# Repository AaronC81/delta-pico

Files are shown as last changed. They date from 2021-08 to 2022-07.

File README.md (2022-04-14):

# Delta Pico

The Delta Pico is a **powerful scientific calculator built around the Raspberry
Pi Pico**.

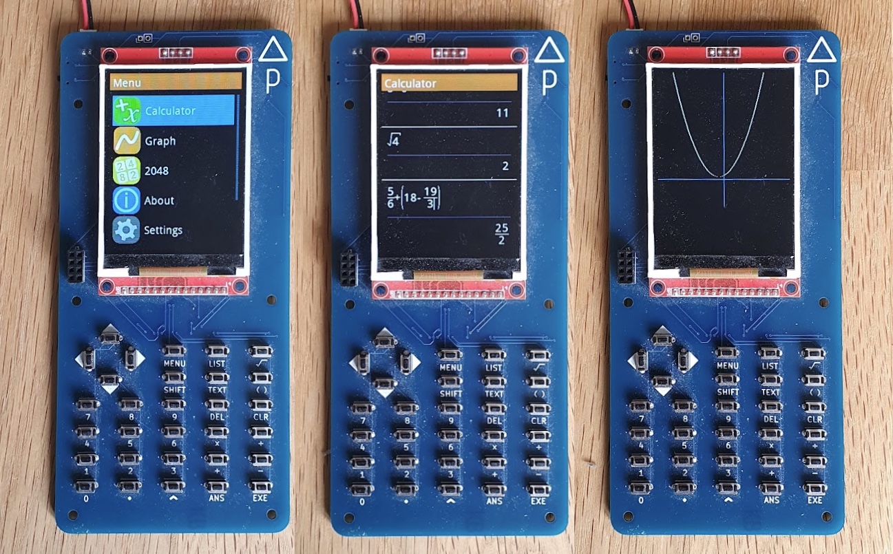
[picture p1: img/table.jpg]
Three images of the Delta Pico calculator on a wooden surface. The first shows the menu interface, with a list of applications such as Calculator and Graph. The second shows the Calculator app, with an expression being edited. The third shows the Graph app, with a parabolic graph plot.


A follow-on project from my [Delta
M0](https://github.com/AaronC81/delta-m0), this calculator is much larger
and significantly more capable, with a 2.8" 240x320 colour display and 30 keys.

The Delta Pico is powered by the [rbop](https://github.com/AaronC81/rbop)
mathematical engine, for gorgeous textbook-style input.

The Delta Pico's software is written in Rust. The hardware abstraction layer is
separate to the user software, theoretically allowing the operating system to
run on other hardware which supports embedded Rust!

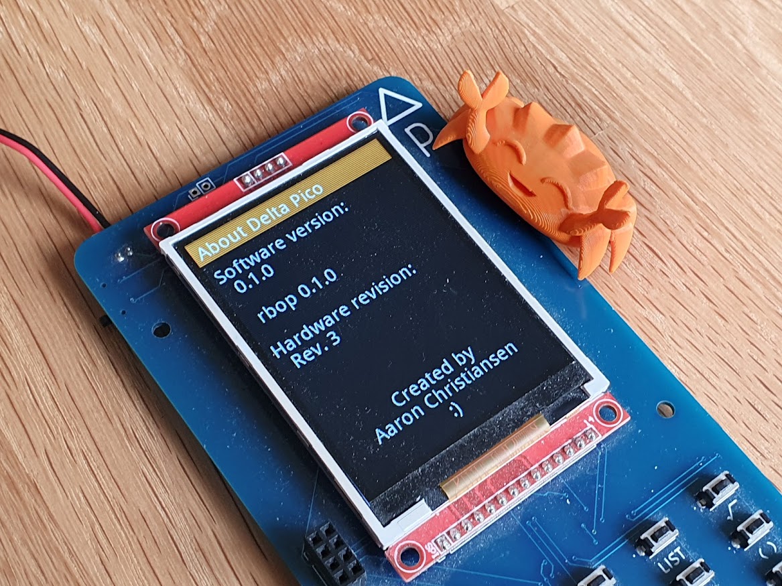
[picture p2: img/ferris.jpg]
Ferris, the Rust mascot, a crab, sitting on top of the Delta Pico


## Building

### Dependencies

You will likely need a bleeding-edge checkout of rbop, so you should check this
out too and adjust the path in `rust/Cargo.toml` accordingly.

This project has a dependency on FontForge, which is used for compiling fonts
into bitmaps. Install FontForge, and then set the `DELTA_PICO_FFPYTHON`
environment variable to point to its included `ffpython` executable. If you've
done this right, you should be able to run `$DELTA_PICO_FFPYTHON` in your 
terminal (or `%DELTA_PICO_FFPYTHON%` on Windows) and get a Python interactive
prompt.

The build script also uses [elf2uf2-rs](https://github.com/JoNil/elf2uf2-rs) to
flash software to the Pico, so be sure to install this.

### Building and Flashing

With all of the above dependencies sorted, cd into `rust-hal` and run:

```
cargo run
```

With a Pico connected in bootloader mode, this should build the project and
flash it onto your Pico.

## Hardware

The KiCad files for the Delta Pico hardware can be found in the `cad` directory.

There is one error with the first hardware revision; a missing trace in the
button matrix, between the down arrow button and diode D8. This can be easily
fixed with a small piece of wire:

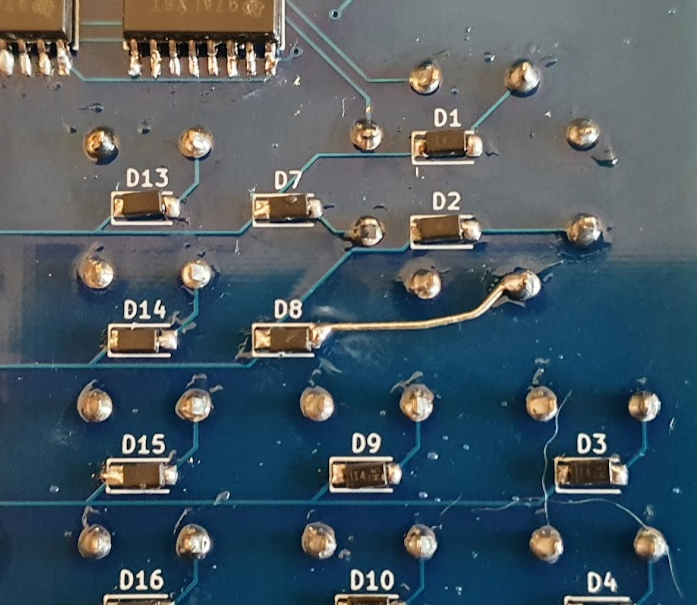
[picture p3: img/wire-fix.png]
A small piece of wire between the down arrow button and diode D8.


## Changelog
### Revision 1
- Initial revision!

### Revision 2
- Add I2C EEPROM chip
- Fix missing trace from "down" button to diode
- Connect display SD pins
- Move Pico further to the side to accommodate SD pins
- Rotate and move expansion socket to not be behind the display

### Revision 3
- Migrate to KiCad 6
- Button layout tweaks
    - The `(` key has been removed and merged into the `)` key to form a single `( )` key
        - rbop treats brackets as a block element, so it isn't possible to have a non-paired
          bracket
        - This means there is no reason to have a separate key for each bracket
    - In place of the `(` key, there is a new `TEXT` key
        - This will be used to toggle a multi-tap text entry mode on the numeric keypad
- Replace the expansion socket with a new debug port
    - 8 pins (4x2) rather than 4 pins
    - 2 of the extra pins are SWCLK and SWDIO (marked SWC and SWD respectively)
    - Other 2 are GPIO 18 and GPIO 19, currently unused
    - Moved to not be in the way of SD card slot
- Connect PCF8574 interrupt pins to GPIO 16/17
- Power-related tweaks
    - Broken out VSYS and GND near the JST battery connector
    - Add MOSFET to allow Pico to turn display on/off
        - Gate controllable with GPIO 22
    - Connect power switch to 3V3 and two GPIOs instead
        - The Pico is now always drawing battery power through VSYS
        - GPIO 26 or 27 will be high in the switch's on or off position respectively
        - In future, the device will soft-power-off by having the Pico turn off the display and
          enter DORMANT mode
    - Add Schottky diode on VSYS, to comply with the datasheet's suggestion

## License

This repository is licensed entirely under the [MIT License](LICENSE), except
for `font/DroidSans.ttf`, which is sourced from Adobe Fonts and licensed under
the [Apache License](https://fonts.adobe.com/variations/1291/eula).

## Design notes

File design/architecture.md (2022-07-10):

# HAL: Hardware Abstraction Layer (aka. Application Framework)

> Note: This was originally called the application framework, and is still named
> `ApplicationFramework` in code, as it was previously used to directly implement applications. Now
> the architecture is different, as the operating system sits in-between hardware and applications,
> but within the code the name has stuck around due to the refactoring effort needed to change it.

The HAL can be found as the `delta-pico-hal` crate, in the `rust-hal` directory. It has three main
responsibilities:

1. Implement `ApplicationFramework` to abstract away the details of the hardware
2. Implement a `main` which starts the OS (by calling `delta_pico_main`)
3. Provide a `global_allocator` so that the OS can allocate on the heap

The main interfaces provided by an `ApplicationFramework` implementation are for the display,
buttons, and storage. Having this common interface means that the HAL can be swapped out while
keeping the OS unchanged, allowing the OS to be completely hardware-agnostic!

The HAL is the binary crate, while the OS is a library crate. This is so that the HAL provides
`main`, which is important in embedded environments where there will be plenty of setup required
before the OS can start (e.g. creating a heap allocator, and peripheral setup).

## Delta Pico HAL

The HAL included in this repository is implemented for the physical Delta Pico. This HAL includes
low-level drivers for communicating with the CAT24C flash memory (over I2C), the PCF8574 logic
expanders used to drive the button matrix (also over I2C), and the ILI9341 display (over SPI).

This HAL utilises the dual-core configuration of the RP2040. Core 0 runs the OS, and drives the
display and storage whenever necessary. Core 1 is entirely dedicated to polling the button matrix
for new button presses; when a press is detected, it is placed into the inter-core FIFO queue. Core
0 will blockingly grab items from this queue when the OS needs user input.

This multi-core architecture is not strictly necessary, but it provides an improved user experience
by meaning that buttons pressed while the OS is busy are stored in a queue, rather than just
dropped.

# OS: Operating System

This is the user-facing software stack, which includes all of the applications, and a set of
higher-level drivers which they are implemented with.

As an example of how the level of abstraction between the HAL and OS drivers differs:

- The button driver provided by the HAL (`ButtonsInterface`) just reports press and release events.
- The `input` function provided by the OS intercepts button presses for system-level functions, such
  as `TEXT` and `MENU`, and deals with them transparently, without the application's involvement.
  It also provides an abstraction of "shifted button presses", whereas the HAL driver will just
  report a press of `SHIFT` and then a press of a regular button separately later.

"Operating system" is a rather generous name for this component - once an application is launched,
it doesn't really do anything besides provide a set of libraries for it to use. There's no
RTOS-style support for tasks or multitasking.

## The Borrow Checker

The relationship between the OS and applications is two-way; the OS launches applications, and
applications call back to the OS to use its APIs. Unfortunately, this isn't something the borrow
checker is able to model particularly well.

Instead, the OS uses `unsafe` code to pass around `OperatingSystemPointer` instances, which are
just raw pointers wrapped in a struct which implements `Deref` and `DerefMut`. This allows
shared, unchecked, mutable access to the OS from anywhere! That's a complete violation of the 
borrow checker's rules, but unless you do something unusual (like replace the entire OS with a new
instance), it shouldn't be too much of a problem.

One potential pitfall is an application making a call which replaces the current application, such
as `launch_application_by_name`. This can invalidate `self` while code is running within the
application, which is pretty much a guaranteed path to some undefined behaviour.

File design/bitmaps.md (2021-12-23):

# Bitmaps

The Delta Pico uses a partially-run-length-encoded bitmap format which is extremely easy to encode
and decode. The Delta Pico has a relatively slow frame time even in the best scenarios, so decoding
speed is an important factor. 

Overview of what's supported:

- Width or height up to 2^16 (65536)
- RGB565 colour, minus any two colours (used as special markers within the image)
- Transparency - only fully transparent or fully opaque, no partial transparency is supported

> Note: This is not the same format as is used for the Delta Pico's [fonts](fonts).

## Encoding Format

A bitmap is encoded as an array of 16-bit integers. The first four items of the array are metadata:

- Image width
- Image height
- A 16-bit marker to represent transparency
- A 16-bit marker to represent the start of run-length encoding

After these elements, pixel data follows. Pixels are encoded with a top-left origin, in columns (not
rows).

Each pixel datum may be one of...

### A 16-bit colour

The colour is simply drawn as encoded.

### The transparency marker

Drawing this pixel will be skipped completely, leaving what was already in that position on the
screen, resulting in a transparent pixel.

### The run-length encoding marker

If the datum is the run-length encoding marker, more elements must be read to gather all required
data. The element following the marker is a count: how many consecutive pixels use the same colour.
The element following the count is the colour to be repeated, which is permitted to be the
transparency marker.

To simplify decoding, run-length pixel encodings may not wrap around the end of a column. Besides
this restriction, run-length encoding is always valid in place of repeated 16-bit colour data and
vice versa: for a colour `A`, pixel encodings `A` and `Y 1 A` are interchangable, though the former
encoding is more space-efficient.

## Example

Take the following 3x5 example image, with 5 unique 16-bit colours represented by letters `A` to
`E`:

```
ABD
ACD
A E
ADE
ADE
```

As with many images in this encoding, there are multiple valid encodings, but the smallest one is
as follows, with array elements visualised as being separated by whitespace for clarity:

```
3 5 X Y 
Y 5 A
B C X D D
D D E E E
```

`3 5 X Y` is the metadata. This image has width 3, height 5, and defines unused colours `X` and `Y`
as transparency and run-length markers respectively.

`Y 5 A` encodes the first column, using a run-length encoding of length 5 repeating the colour `A`.
`A A A A A` would have been an equally valid encoding, but that is longer.

`B C X D D` encodes the second column. The `B` and `C` colours only appear for a single pixel, so
run-length encoding would be a waste of space, but `Y 1 B` and `Y 1 C` would be valid. `X` encodes
the transparent pixel in the middle of the column. Finally, `D D` is used - while the `D` pixels
do continue onto the next column, run-length encoding across columns is not allowed, so `D D` is the
most space-efficient encoding.

`D D E E E` encodes the third and final column, simply encoding all pixels individually. For the `E`
pixels, `Y 3 E` would take up identical space, but requires more decoding logic, so `E E E` is the
preferred form.

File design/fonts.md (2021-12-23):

# Fonts

The Delta Pico uses a custom monochrome font format with transparency support, so that fonts can be
anti-aliased against their background. Key details:

- Each glyph can be up to 255x255
- 4 bits of alpha per pixel (0-15)
- Only ASCII characters are supported

## Glyph Format

Compared to the [16-bit colour bitmap format](bitmaps) used for images, this font format is more
more simple.

The first byte is the width of the glyph, and the second byte is the height of the glyph. After
this short header, every other byte is pixel data. Pixels are encoded with a top-left origin, in 
columns (not rows).

Every **nibble** (4 bits) after the header is the alpha of that pixel, i.e. how transparent is
should be when drawn. 0 means that pixel is fully transparent and won't be drawn at all, 15 (0xF)
means it'll be drawn fully opaque, and a value between the two will blend the font and background
colours.

If the glyph contains an odd number of pixels, so that the alpha nibbles do not fit evenly into the 
number of bytes, the final nibble will be ignored.

## Font Format

Fonts are 256-element arrays of pointers to ASCII glyphs: indexing the font array with a particular
ASCII value will return a pointer to the glyph data for that character.

If a font does not support a particular ASCII character, it should return `NULL` instead. These
characters will be omitted when rendering text.

## Text Rendering

The Delta Pico's text renderer is very naive. It does not apply any character spacing - spacing must
be included within the glyph. Any fully transparent pixels such as spacing will also be considered
when performing string length measurements, so you may wish to apply spacing evenly to both sides of
a glyph to ensure it looks correct when the OS centers text.

There is one special case when rendering: the newline character `\n` (ASCII dec 10, hex 0xA) will
never be rendered as a character, even in the font provides a glyph for it. Instead, the text cursor
will set the current X position to 0, and increase the Y position by the height of the glyph for `A`
(ASCII dec 65, hex 0x41) provided by the font.

This special case does not apply to any other control characters - they have no effect on the
cursor, and it is possible to provide glyphs for those which would be rendered.

## Compression

Glyphs are not currently compressed in any way, though this may be a good improvement for the
future. Run-length encoding is unlikely to yield much of a benefit for the characters themselves,
but it could be very beneficial for the large transparent areas around characters.

An easy improvement would be to allow each glyph to specify a "glyph size", "bitmap size", and
"bitmap offset". When drawn, the glyph would advance the cursor by its "glyph size", but the
transparency padding the bitmap can be removed, and instead only draw a bitmap within a smaller
bounding box defined by the "bitmap size" and "bitmap offset".

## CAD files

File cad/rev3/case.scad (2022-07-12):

delta_pico_width = 78.2;
delta_pico_height = 166.8;
delta_pico_corner_radius = 4.5;

border_size = 3;

power_switch_offset = 8;
power_switch_length = 10;
jst_offset = 4;
jst_length = 9;
usb_offset = 50;
usb_length = 14;

screws_edge_distance = 6;
bottom_screws_offset = 6;
middle_screws_offset = 76.1;
top_screw_offset = 142.25;

edge_cutout_size = border_size + 1;

base_height = 4;
screw_depth = 6;
peg_height = 5;

module delta_pico() {
    translate([delta_pico_corner_radius, delta_pico_corner_radius])
    minkowski() {
        circle(delta_pico_corner_radius);
        square([
            delta_pico_width - delta_pico_corner_radius * 2,
            delta_pico_height - delta_pico_corner_radius * 2
        ]);
    }
}

module delta_pico_outline() {
    difference() {
        translate([border_size + delta_pico_corner_radius, border_size + delta_pico_corner_radius])
        minkowski() {
            circle(border_size + delta_pico_corner_radius);
            square([
                delta_pico_width - delta_pico_corner_radius * 2,
                delta_pico_height - delta_pico_corner_radius * 2
            ]);
        }

        // Cut out the calculator itself
        translate([border_size, border_size])
        delta_pico();
    }
}

module delta_pico_outline_with_cutouts() {
    difference() {
        delta_pico_outline();
        
        // Cut out the power switch
        translate([0, border_size + delta_pico_height - power_switch_offset - power_switch_length])
        square([edge_cutout_size, power_switch_length]);
        
        // Cut out the JST connector
        translate([border_size + jst_offset, border_size + delta_pico_height - 1])
        square([jst_length, edge_cutout_size]);
        
        // Cut out the USB port
        translate([border_size + usb_offset, border_size + delta_pico_height - 1])
        square([usb_length, edge_cutout_size]);
    }
}

module screw_hole() {
    linear_extrude(screw_depth)
    circle(d=2.7, $fn=15);
}

module screw_peg() {
    linear_extrude(peg_height)
    circle(d=6, $fn=15);
}

module base() {
    difference() {
        union() {
            linear_extrude(base_height)
            delta_pico_outline();
            
            translate([border_size, border_size]) {
                linear_extrude(base_height)
                delta_pico();
                
                translate([6, 6, base_height])
                screw_peg();
                
                translate([delta_pico_width - 6, 6, base_height])
                screw_peg();
                
                translate([6, middle_screws_offset, base_height])
                screw_peg();
                
                translate([delta_pico_width - 6, middle_screws_offset, base_height])
                screw_peg();
                
                translate([6, top_screw_offset, base_height])
                screw_peg();
            }
        }
        
        translate([border_size, border_size]) {
            screw_offset = base_height - screw_depth + peg_height;
            
            translate([6, 6, screw_offset])
            screw_hole();
            
            translate([delta_pico_width - 6, 6, screw_offset])
            screw_hole();
            
            translate([6, middle_screws_offset, screw_offset])
            screw_hole();
                
            translate([delta_pico_width - 6, middle_screws_offset, screw_offset])
            screw_hole();
            
            translate([6, top_screw_offset, screw_offset])
            screw_hole();
        }
    }
}

module logo() {
    translate([3 - 60 / 2, 3 - 50 / 2])
    minkowski() {
        polygon([
            [0, 0],
            [30, 50],
            [60, 0],
            [0, 0.1],
            [60, 0.1],
            [30, 50.1],
            [0, 0.1]
        ]);
        circle(4, $fn=30);
    }
}

difference() {
    base();

    translate([delta_pico_width / 2, delta_pico_height / 2])
    linear_extrude(base_height - 2.5)
    logo();
}

translate([0, 0, base_height])
linear_extrude(7.5)
delta_pico_outline_with_cutouts();

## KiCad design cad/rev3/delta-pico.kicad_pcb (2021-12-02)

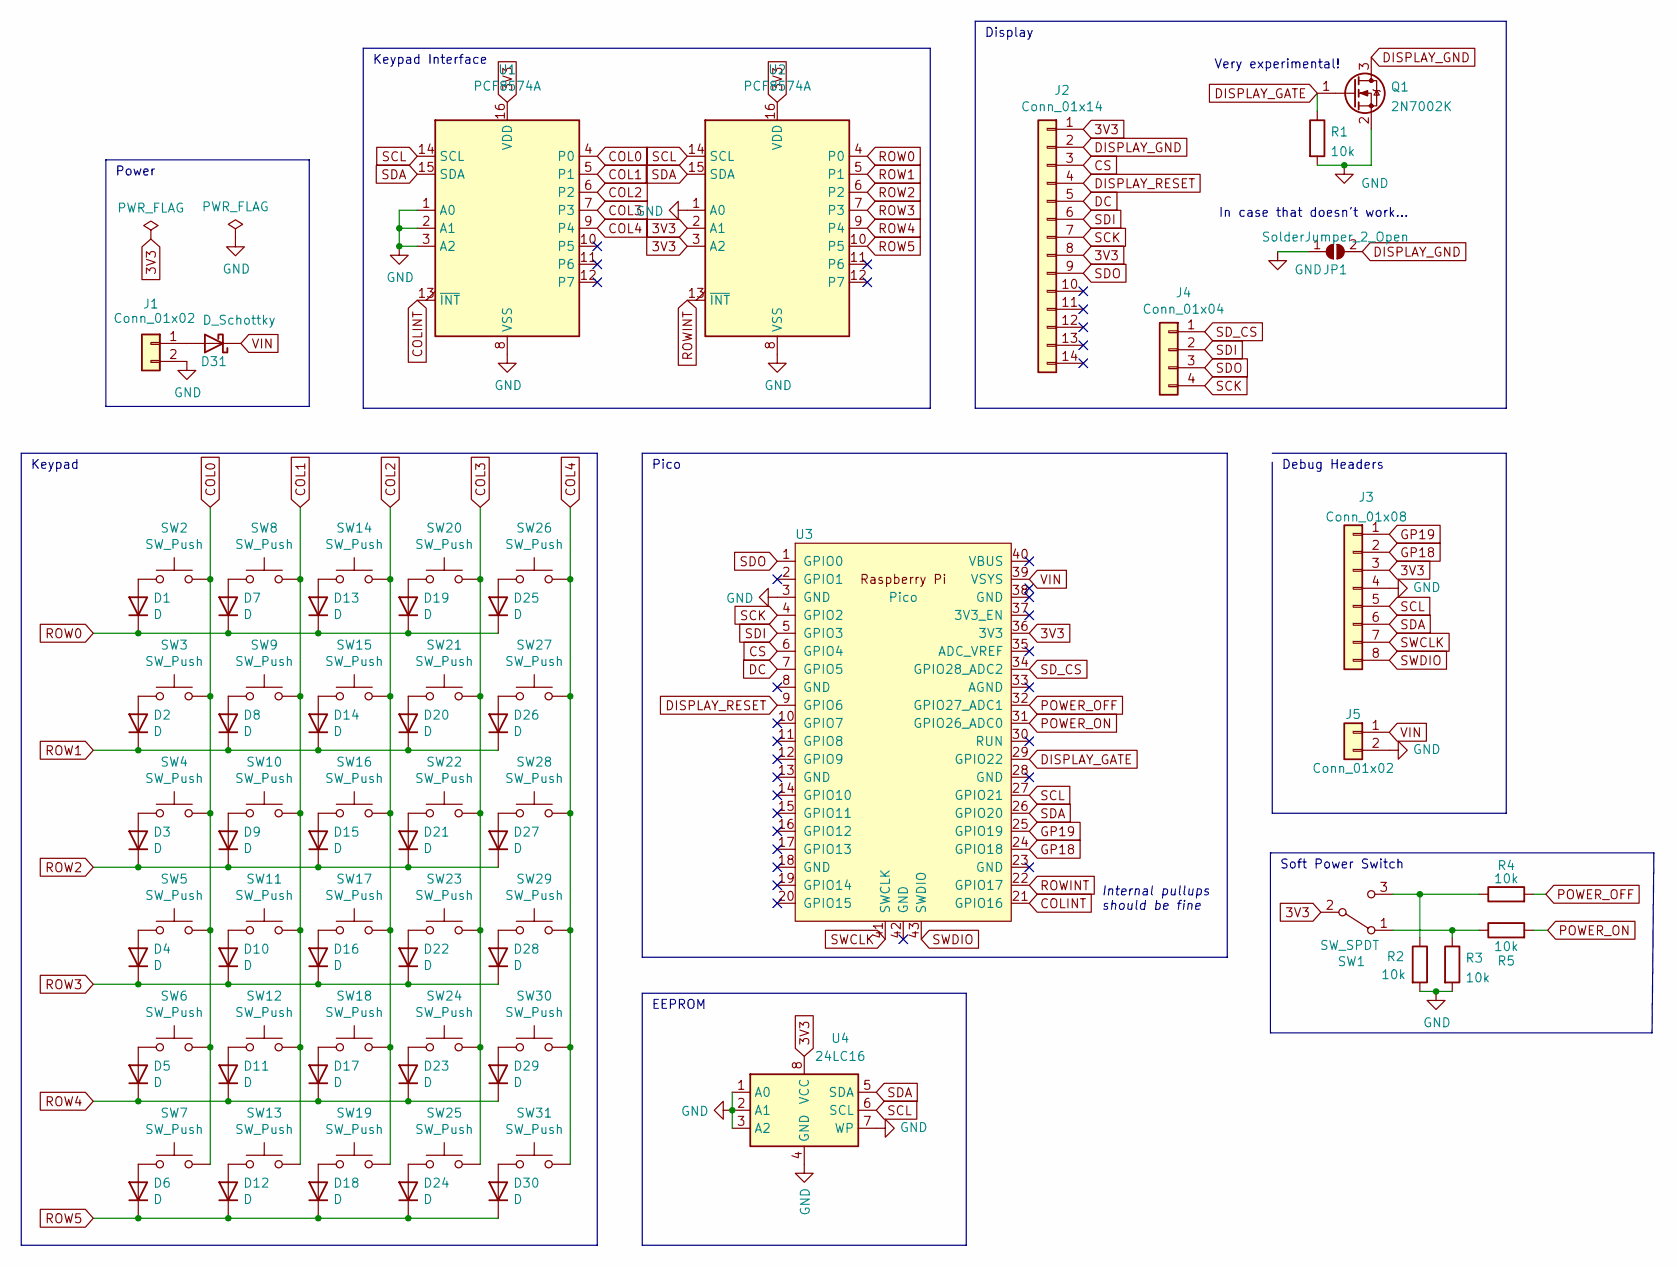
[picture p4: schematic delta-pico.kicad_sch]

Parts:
D1, D2, D3, D4, D5, D6, D7, D8, D9, D10, D11, D12, D13, D14, D15, D16, D17, D18, D19, D20, D21, D22, D23, D24, D25, D26, D27, D28, D29, D30: D; D_SOD-123
D31: D_Schottky; D_SOD-123
J1: Conn_01x02; JST_PH_S2B-PH-K_1x02_P2.00mm_Horizontal
J2: Conn_01x14; PinHeader_1x14_P2.54mm_Vertical
J3: Conn_01x08; PinHeader_2x04_P2.54mm_Vertical
J4: Conn_01x04; PinHeader_1x04_P2.54mm_Vertical
J5: Conn_01x02; PinHeader_1x02_P2.54mm_Vertical
JP1: SolderJumper_2_Open; SolderJumper-2_P1.3mm_Open_RoundedPad1.0x1.5mm
Q1: 2N7002K; SOT-23
R1, R2, R3, R4, R5: 10k; R_0603_1608Metric_Pad0.98x0.95mm_HandSolder
SW1: SW_SPDT; SW_SPDT_CK-JS102011SAQN
SW2, SW3, SW4, SW5, SW6, SW7, SW8, SW9, SW10, SW11, SW12, SW13, SW14, SW15, SW16, SW17, SW18, SW19, SW20, SW21, SW22, SW23, SW24, SW25, SW26, SW27, SW28, SW29, SW30, SW31: SW_Push; PTS636SL43LFS
U1, U2: PCF8574A; SOIC-16W_7.5x10.3mm_P1.27mm
U3: Pico; RPi_Pico_SMD_TH
U4: 24LC16; SOIC-8_3.9x4.9mm_P1.27mm

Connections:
3V3: J2.1, J2.8, J3.3, SW1.2 (B), U1.16 (VDD), U2.2 (A1), U2.3 (A2), U2.16 (VDD), U3.36 (3V3), U4.8 (VCC)
COL0: SW2.2, SW3.2, SW4.2, SW5.2, SW6.2, SW7.2, U1.4 (P0)
COL1: SW8.2, SW9.2, SW10.2, SW11.2, SW12.2, SW13.2, U1.5 (P1)
COL2: SW14.2, SW15.2, SW16.2, SW17.2, SW18.2, SW19.2, U1.6 (P2)
COL3: SW20.2, SW21.2, SW22.2, SW23.2, SW24.2, SW25.2, U1.7 (P3)
COL4: SW26.2, SW27.2, SW28.2, SW29.2, SW30.2, SW31.2, U1.9 (P4)
COLINT: U1.13 (~INT), U3.21 (GPIO16)
CS: J2.3, U3.6 (GPIO4)
DC: J2.5, U3.7 (GPIO5)
DISPLAY_GATE: Q1.1 (G), R1.1, U3.29 (GPIO22)
DISPLAY_GND: J2.2, JP1.2 (B), Q1.3 (D)
DISPLAY_RESET: J2.4, U3.9 (GPIO6)
GND: J1.2, J3.4, J5.2, JP1.1 (A), Q1.2 (S), R1.2, R2.2, R3.2, U1.1 (A0), U1.2 (A1), U1.3 (A2), U1.8 (VSS), U2.1 (A0), U2.8 (VSS), U3.3 (GND), U4.1 (A0), U4.2 (A1), U4.3 (A2), U4.4 (GND), U4.7 (WP)
GP18: J3.2, U3.24 (GPIO18)
GP19: J3.1, U3.25 (GPIO19)
unnamed: D1.2 (A), SW2.1
unnamed: D2.2 (A), SW3.1
unnamed: D3.2 (A), SW4.1
unnamed: D4.2 (A), SW5.1
unnamed: D5.2 (A), SW6.1
unnamed: D6.2 (A), SW7.1
unnamed: D7.2 (A), SW8.1
unnamed: D8.2 (A), SW9.1
unnamed: D9.2 (A), SW10.1
unnamed: D10.2 (A), SW11.1
unnamed: D11.2 (A), SW12.1
unnamed: D12.2 (A), SW13.1
unnamed: D13.2 (A), SW14.1
unnamed: D14.2 (A), SW15.1
unnamed: D15.2 (A), SW16.1
unnamed: D16.2 (A), SW17.1
unnamed: D17.2 (A), SW18.1
unnamed: D18.2 (A), SW19.1
unnamed: D19.2 (A), SW20.1
unnamed: D20.2 (A), SW21.1
unnamed: D21.2 (A), SW22.1
unnamed: D22.2 (A), SW23.1
unnamed: D23.2 (A), SW24.1
unnamed: D24.2 (A), SW25.1
unnamed: D25.2 (A), SW26.1
unnamed: D26.2 (A), SW27.1
unnamed: D27.2 (A), SW28.1
unnamed: D28.2 (A), SW29.1
unnamed: D29.2 (A), SW30.1
unnamed: D30.2 (A), SW31.1
unnamed: D31.2 (A), J1.1
unnamed: R3.1, R5.1, SW1.1 (A)
unnamed: R2.1, R4.1, SW1.3 (C)
POWER_OFF: R4.2, U3.32 (GPIO27_ADC1)
POWER_ON: R5.2, U3.31 (GPIO26_ADC0)
ROW0: D1.1 (K), D7.1 (K), D13.1 (K), D19.1 (K), D25.1 (K), U2.4 (P0)
ROW1: D2.1 (K), D8.1 (K), D14.1 (K), D20.1 (K), D26.1 (K), U2.5 (P1)
ROW2: D3.1 (K), D9.1 (K), D15.1 (K), D21.1 (K), D27.1 (K), U2.6 (P2)
ROW3: D4.1 (K), D10.1 (K), D16.1 (K), D22.1 (K), D28.1 (K), U2.7 (P3)
ROW4: D5.1 (K), D11.1 (K), D17.1 (K), D23.1 (K), D29.1 (K), U2.9 (P4)
ROW5: D6.1 (K), D12.1 (K), D18.1 (K), D24.1 (K), D30.1 (K), U2.10 (P5)
ROWINT: U2.13 (~INT), U3.22 (GPIO17)
SCK: J2.7, J4.4, U3.4 (GPIO2)
SCL: J3.5, U1.14 (SCL), U2.14 (SCL), U3.27 (GPIO21), U4.6 (SCL)
SDA: J3.6, U1.15 (SDA), U2.15 (SDA), U3.26 (GPIO20), U4.5 (SDA)
SDI: J2.6, J4.2, U3.5 (GPIO3)
SDO: J2.9, J4.3, U3.1 (GPIO0)
SD_CS: J4.1, U3.34 (GPIO28_ADC2)
SWCLK: J3.7, U3.41 (SWCLK)
SWDIO: J3.8, U3.43 (SWDIO)
VIN: D31.1 (K), J5.1, U3.39 (VSYS)

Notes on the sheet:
Internal pullups should be fine
Display
Very experimental!
Keypad Interface
In case that doesn't work...
Pico
Soft Power Switch
Power
EEPROM
Debug Headers
Keypad

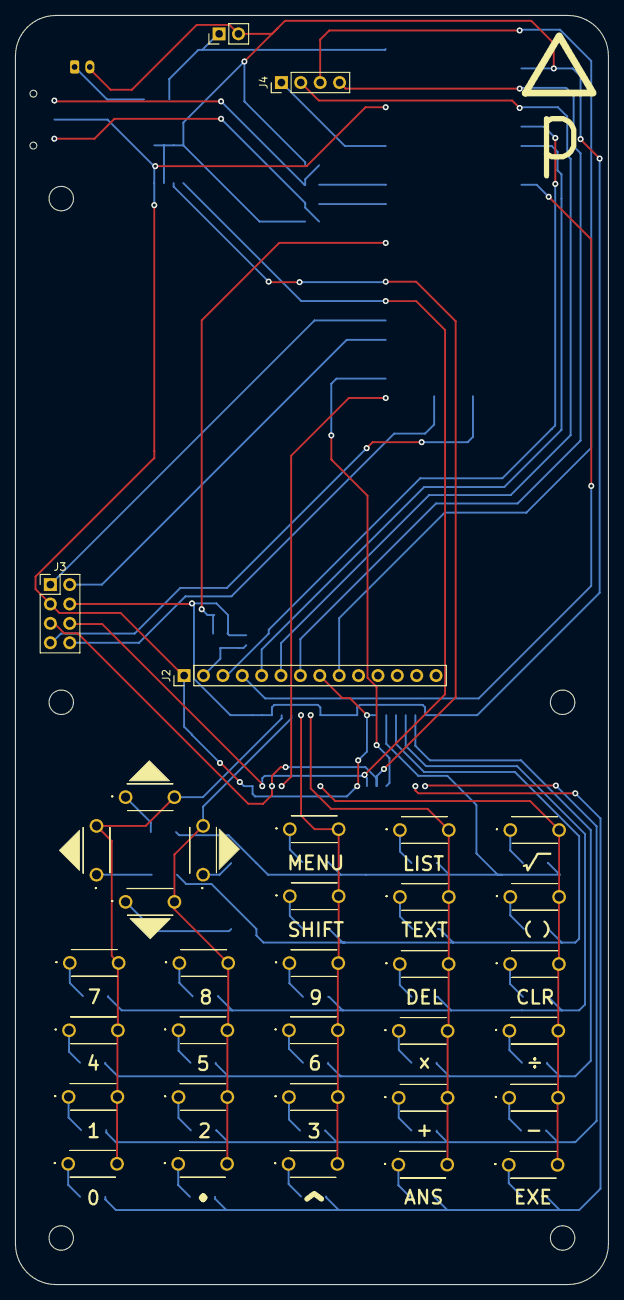
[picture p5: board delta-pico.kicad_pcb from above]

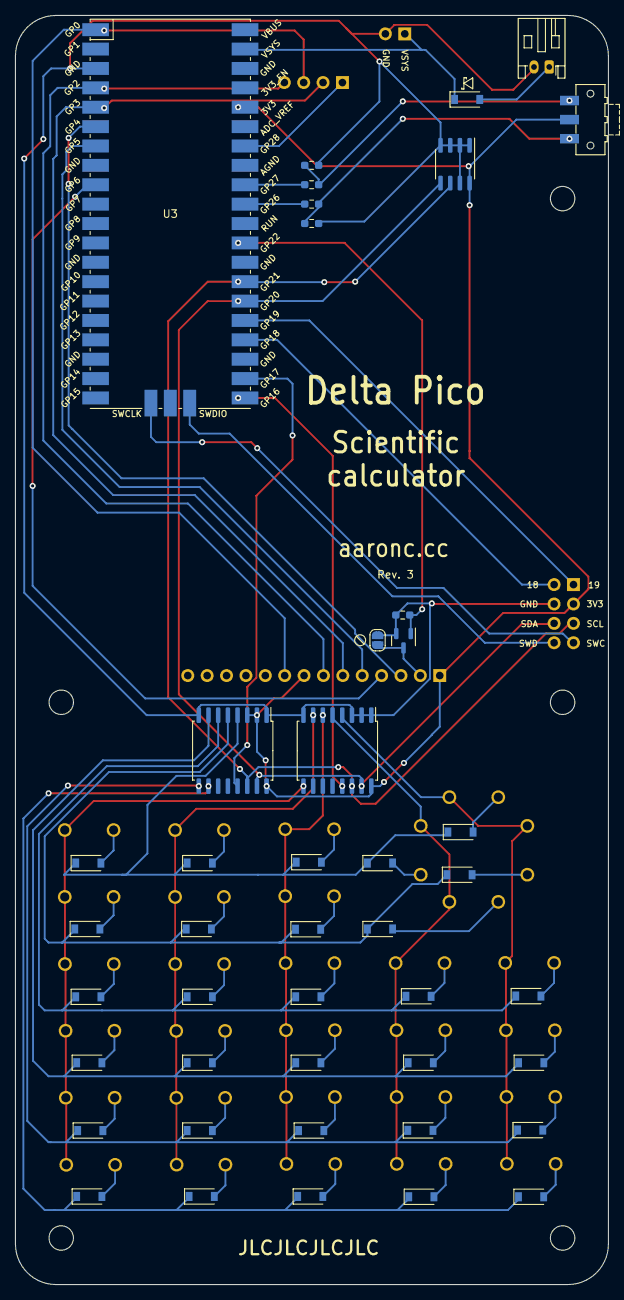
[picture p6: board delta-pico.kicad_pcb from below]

Board: 2 copper layers, 77.7 x 166.3 mm, 78 parts (44 on the bottom side), 66 nets.

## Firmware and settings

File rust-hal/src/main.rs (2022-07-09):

#![no_std]
#![no_main]
#![feature(alloc_error_handler)]
#![feature(default_alloc_error_handler)]

extern crate alloc;

mod ili9341;
mod pcf8574;
mod cat24c;
mod button_matrix;
mod rev;

use alloc::string::{String, ToString};
use alloc_cortex_m::CortexMHeap;
use button_matrix::{RawButtonEvent, ButtonMatrix};
use cat24c::Cat24C;
use cortex_m_rt::entry;
use delta_pico_rust::{interface::{DisplayInterface, ApplicationFramework, ButtonsInterface, ButtonEvent, StorageInterface, ButtonInput}, delta_pico_main, graphics::Sprite};
use embedded_hal::{digital::v2::{OutputPin}, spi::MODE_0, blocking::delay::DelayMs, blocking::i2c::{Write, Read}};
use embedded_time::{fixed_point::FixedPoint, rate::Extensions};
use ili9341::Ili9341;
use rp_pico as bsp;
use bsp::{hal::{
    clocks::{init_clocks_and_plls, Clock},
    pac,
    sio::{Sio, SioFifo, Spinlock},
    watchdog::Watchdog,
    spi::{Spi, SpiDevice}, gpio::{FunctionSpi, PinId, FunctionI2C, Pin, bank0::{Gpio20, Gpio21}}, I2C, Timer, multicore::{Stack, Multicore},
}, pac::I2C0};

#[global_allocator]
static ALLOCATOR: CortexMHeap = CortexMHeap::empty();
const HEAP_SIZE: usize = 240_000;

/// Asserts that a reference will be valid for the entire lifetime of the program, and returns a new
/// reference to the same object, but with a `'static` lifetime.
/// 
/// This is *very* unsafe when used incorrectly, since it can easily create invalid references.
/// It's also used to create multiple mutable references to the same value, which isn't allowed.
/// However, in our embedded world, we can be reasonably confident that some objects do in fact live
/// forever, even if the compiler doesn't agree with us. (Or at the very least, if these objects are
/// ever dropped, something has gone wrong enough that it won't matter any more!)
/// 
/// This avoids having to associate lifetimes with our framework implementation, which isn't
/// possible due to the `'static` bounds enforced by the OS.
fn lives_forever<T: ?Sized>(t: &mut T) -> &'static mut T {
    unsafe { (t as *mut T).as_mut().unwrap() }
}

/// The I2C bus peripheral, used to communicate with the display and storage.
/// 
/// Stored in a global so that core 1 can access it too - the HAL doesn't seem to provide a method
/// to get access to an I2C peripheral without re-initialising it, so it can't be stolen like most
/// other peripherals can.
static mut I2C: Option<&'static mut I2C<I2C0, (Pin<Gpio20, FunctionI2C>, Pin<Gpio21, FunctionI2C>)>> = None;

/// A spinlock with an arbitrarily-chosen number, used to sychronise access to the I2C bus.
type I2CSpinlock = Spinlock<8>;

/// The clock speed of the system clock in hertz. Global so that it can be read by core 1 to set up
/// delay timing.
static mut SYSTEM_CLOCK_HZ: u32 = 0;

#[entry]
fn main() -> ! {
    // Set up allocator
    {
        use core::mem::MaybeUninit;
        static mut HEAP: [MaybeUninit<u8>; HEAP_SIZE] = [MaybeUninit::uninit(); HEAP_SIZE];
        unsafe {
            ALLOCATOR.init(HEAP.as_ptr() as usize, HEAP_SIZE)
        }
    }

    let mut pac = pac::Peripherals::take().unwrap();
    let core = pac::CorePeripherals::take().unwrap();
    let mut watchdog = Watchdog::new(pac.WATCHDOG);
    let mut sio = Sio::new(pac.SIO);

    // External high-speed crystal on the pico board is 12Mhz
    let external_xtal_freq_hz = 12_000_000u32;
    let clocks = init_clocks_and_plls(
        external_xtal_freq_hz,
        pac.XOSC,
        pac.CLOCKS,
        pac.PLL_SYS,
        pac.PLL_USB,
        &mut pac.RESETS,
        &mut watchdog,
    )
    .ok()
    .unwrap();

    unsafe { SYSTEM_CLOCK_HZ = clocks.system_clock.freq().integer() };
    let mut delay = cortex_m::delay::Delay::new(core.SYST, clocks.system_clock.freq().integer());
    let timer = Timer::new(pac.TIMER, &mut pac.RESETS);

    // Kick off core 1, which gathers button presses and relays them to core 0 over a FIFO
    // Even though this is far too early (we haven't set up I2C yet), we need to start it here
    // because `pins` moves part of `sio`, so we can't mutably borrow it any more
    // To prevent issues, it'll block until we drop the lock for the first time
    let _lock = I2CSpinlock::claim();
    let mut mc = Multicore::new(&mut pac.PSM, &mut pac.PPB, &mut sio);
    let cores = mc.cores();
    let core1 = &mut cores[1];
    let _test = core1.spawn(core1_task, unsafe { &mut CORE1_STACK.mem });

    let pins = bsp::Pins::new(
        pac.IO_BANK0,
        pac.PADS_BANK0,
        sio.gpio_bank0,
        &mut pac.RESETS,
    );

    let mut led = pins.led.into_push_pull_output();
    led.set_high().unwrap();

    // Chip-select display
    let mut cs_pin = pins.gpio4.into_push_pull_output();
    cs_pin.set_low().unwrap();

    // Set up SPI and pins
    let spi = Spi::<_, _, 8>::new(pac.SPI0);
    let spi = spi.init(
        &mut pac.RESETS,
        clocks.peripheral_clock.freq(),
        70_000_000.Hz(),
        &MODE_0,
    );
    let _miso = pins.gpio0.into_mode::<FunctionSpi>();
    let _mosi = pins.gpio3.into_mode::<FunctionSpi>();
    let _sclk = pins.gpio2.into_mode::<FunctionSpi>();

    // Hardware reset
    let mut rst_pin = pins.gpio6.into_push_pull_output();
    rst_pin.set_low().unwrap();
    delay.delay_ms(50);
    rst_pin.set_high().unwrap();
    delay.delay_ms(50);

    // DC pin
    let dc_pin = pins.gpio5.into_push_pull_output();

    // Construct ILI9341 instance
    let ili = ili9341::Ili9341::new(
        240, 320,
        spi,
        dc_pin,
        rst_pin,
        lives_forever(&mut delay),
    ).init().unwrap();

    // Construct PCF8574 instances
    let sda_pin = pins.gpio20.into_mode::<FunctionI2C>();
    let scl_pin = pins.gpio21.into_mode::<FunctionI2C>();
    let mut i2c = I2C::i2c0(
        pac.I2C0,
        sda_pin,
        scl_pin,
        400.kHz(),
        &mut pac.RESETS,
        clocks.peripheral_clock,
    );

    // Share the bus with the other core, and release the lock to allow it to start
    unsafe { I2C = Some(lives_forever(&mut i2c)); }
    drop(_lock);

    // Init flash storage
    let flash = Cat24C::new(
        0x50, 
        lives_forever(&mut i2c),
        lives_forever(&mut delay),
    );

    let framework = FrameworkImpl {
        display: DisplayImpl { ili },
        buttons: ButtonsImpl { fifo: lives_forever(&mut sio.fifo) },
        storage: StorageImpl { flash },
        
        timer,
    };
    delta_pico_main(framework);

    loop {
        panic!("ended")
    }
}

struct DisplayImpl<SpiD: SpiDevice, DcPin: PinId, RstPin: PinId, Delay: DelayMs<u8> + 'static> {
    ili: Ili9341<ili9341::Enabled, SpiD, DcPin, RstPin, Delay>,
}

impl<SpiD: SpiDevice, DcPin: PinId, RstPin: PinId, Delay: DelayMs<u8>> DisplayInterface for DisplayImpl<SpiD, DcPin, RstPin, Delay> {
    fn width(&self) -> u16 { 240 }
    fn height(&self) -> u16 { 320 }

    fn draw_display_sprite(&mut self, sprite: &Sprite) {
        self.ili.draw_screen_sprite(sprite).unwrap();
    }
}

struct ButtonsImpl {
    fifo: &'static mut SioFifo,
}

impl ButtonsInterface for ButtonsImpl {
    fn wait_event(&mut self) -> delta_pico_rust::interface::ButtonEvent {
        let raw_button = self.fifo.read_blocking();

        match RawButtonEvent::from_u32(raw_button) {
            RawButtonEvent::Press(row, col) => {
                let input = rev::BUTTON_MAPPING[row as usize][col as usize];
                return ButtonEvent::Press(input)
            }

            RawButtonEvent::Release(row, col) => {
                let input = rev::BUTTON_MAPPING[row as usize][col as usize];
                return ButtonEvent::Release(input)
            }
        };
    }

    fn poll_event(&mut self) -> Option<delta_pico_rust::interface::ButtonEvent> {
        todo!()
    }
}

struct StorageImpl<
    StorageI2CDevice: Write<Error = StorageError> + Read<Error = StorageError> + 'static,
    StorageError,
    Delay: DelayMs<u8> + 'static,
> {
    flash: Cat24C<StorageI2CDevice, StorageError, Delay>,
}

impl<
    StorageI2CDevice: Write<Error = StorageError> + Read<Error = StorageError>,
    StorageError,
    Delay: DelayMs<u8> + 'static,
> StorageInterface for StorageImpl<StorageI2CDevice, StorageError, Delay> {
    fn is_connected(&mut self) -> bool {
        let _lock = I2CSpinlock::claim();
        self.flash.is_connected()
    }
    fn is_busy(&mut self) -> bool {
        let _lock = I2CSpinlock::claim();
        self.flash.is_busy()
    }

    fn write(&mut self, address: u16, bytes: &[u8]) -> Option<()> {
        let _lock = I2CSpinlock::claim();
        self.flash.write(address, bytes).ok()
    }

    fn read(&mut self, address: u16, bytes: &mut [u8]) -> Option<()> {
        let _lock = I2CSpinlock::claim();
        self.flash.read(address, bytes).ok()
    }

    // TODO No-ops for now
    fn acquire_priority(&mut self) {}
    fn release_priority(&mut self) {}
}

struct FrameworkImpl<
    SpiD: SpiDevice,
    DcPin: PinId,
    RstPin: PinId,
    Delay: DelayMs<u8> + 'static,

    StorageI2CDevice: Write<Error = StorageError> + Read<Error = StorageError> + 'static,
    StorageError,
> {
    display: DisplayImpl<SpiD, DcPin, RstPin, Delay>,
    buttons: ButtonsImpl,
    storage: StorageImpl<StorageI2CDevice, StorageError, Delay>,
    timer: Timer,
}

impl<
    SpiD: SpiDevice,
    DcPin: PinId,
    RstPin: PinId,
    Delay: DelayMs<u8> + 'static,

    StorageI2CDevice: Write<Error = StorageError> + Read<Error = StorageError>,
    StorageError,
> ApplicationFramework for FrameworkImpl<SpiD, DcPin, RstPin, Delay, StorageI2CDevice, StorageError> {
    type DisplayI = DisplayImpl<SpiD, DcPin, RstPin, Delay>;
    type ButtonsI = ButtonsImpl;
    type StorageI = StorageImpl<StorageI2CDevice, StorageError, Delay>;

    fn display(&self) -> &Self::DisplayI { &self.display }
    fn display_mut(&mut self) -> &mut Self::DisplayI { &mut self.display }

    fn buttons(&self) -> &Self::ButtonsI { &self.buttons }
    fn buttons_mut(&mut self) -> &mut Self::ButtonsI { &mut self.buttons }

    fn storage(&self) -> &Self::StorageI { &self.storage }
    fn storage_mut(&mut self) -> &mut Self::StorageI { &mut self.storage }

    fn hardware_revision(&self) -> String { rev::REVISION_NAME.to_string() }

    fn reboot_into_bootloader(&mut self) -> ! {
        // Awww, yeah!
        // This is a translation of the parts of...
        //   - https://github.com/raspberrypi/pico-sdk/blob/master/src/rp2_common/pico_bootrom/bootrom.c
        //   - https://github.com/raspberrypi/pico-sdk/blob/master/src/rp2_common/pico_bootrom/include/pico/bootrom.h
        // ...required to call `reset_usb_boot`.
        // Nothing super fancy is going on here, just lots of casting pointers around.
        // The mem::transmute calls are required because Rust doesn't allow you to cast `*const _`
        // to `extern "C" fn(...) -> _`, even though the latter is still just a pointer in memory.
        unsafe {
            // Resolve a function which allows us to look up items in ROM tables
            let rom_table_lookup_fn_addr = *(0x18 as *const u16) as *const ();
            let rom_table_lookup_fn: extern "C" fn(*const u16, u32) -> *const () = core::mem::transmute(rom_table_lookup_fn_addr);
            
            // Use that function to look up the address of the USB bootloader function
            let usb_boot_fn_code = (('B' as u32) << 8) | ('U' as u32);
            let func_table = *(0x14 as *const u16) as *const u16;
            let usb_boot_fn_addr = rom_table_lookup_fn(func_table, usb_boot_fn_code);

            // Call that function
            let usb_boot_fn: extern "C" fn(u32, u32) = core::mem::transmute(usb_boot_fn_addr);
            usb_boot_fn(0, 0);
        }
        panic!("failed to access bootloader")
    }

    fn micros(&self) -> u64 {
        self.timer.get_counter()
    }

    fn millis(&self) -> u64 {
        self.micros() / 1000
    }

    fn memory_usage(&self) -> (usize, usize) {
        (ALLOCATOR.used(), HEAP_SIZE)
    }

    fn debug(&self, _message: &str) {
        // Not implemented
    }

    fn should_run_tests(&mut self) -> bool {
        // Hold DEL on boot
        // The OS has never queried for input before this, so if delete was pressed, it's still in
        // the queue
        let pac = unsafe { pac::Peripherals::steal() };
        let mut sio = Sio::new(pac.SIO);
        if let Some(encoded) = sio.fifo.read() {
            if let RawButtonEvent::Press(row, col) = RawButtonEvent::from_u32(encoded) {
                let button = rev::BUTTON_MAPPING[row as usize][col as usize];
                if button == ButtonInput::Delete {
                    return true;
                }    
            }
        }
                
        false
    }
}

static mut CORE1_STACK: Stack<4096> = Stack::new();
fn core1_task() -> ! {
    // Grab some important peripherals
    let pac = unsafe { pac::Peripherals::steal() };
    let core = unsafe { pac::CorePeripherals::steal() };
    let mut sio = Sio::new(pac.SIO);
    let mut delay = cortex_m::delay::Delay::new(core.SYST, unsafe { SYSTEM_CLOCK_HZ });

    // Core 0 holds the I2C lock until it's shared the bus with us, so block on that
    let _lock = I2CSpinlock::claim();
    drop(_lock);
    let i2c = unsafe { I2C.take().unwrap() };

    // Set up button matrix expanders
    let col_pcf = pcf8574::Pcf8574::new(0x38, lives_forever(i2c));
    let row_pcf = pcf8574::Pcf8574::new(0x3E, lives_forever(i2c));

    // Init button matrix
    let mut buttons = ButtonMatrix::new(
        row_pcf,
        col_pcf, 
        lives_forever(&mut delay),
    );    

    // For the rest of time, loop looking for buttons
    loop {
        let _lock = I2CSpinlock::claim();
        if let Ok(Some(btn)) = buttons.get_event(false) {
            sio.fifo.write(btn.to_u32());
        }
        drop(_lock);

        // We need to give the storage peripheral a little bit of time to claim the lock if it's
        // waiting
        delay.delay_ms(1);
    }
}

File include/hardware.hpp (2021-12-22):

#pragma once

extern "C" {
    #include "delta_pico_rust.h"
}

#define I2C_SDA_PIN 20
#define I2C_SCL_PIN 21

#define I2C_EXPANDER_ADDRESS_1 0x38
#define I2C_EXPANDER_ADDRESS_2 0x3E

#define ILI9341_MISO_PIN 0
#define ILI9341_MOSI_PIN 3
#define ILI9341_SCLK_PIN 2
#define ILI9341_DC_PIN 5
#define ILI9341_CS_PIN 4
#define ILI9341_RST_PIN 6
#define ILI9341_POWER_PIN 28

#define CAT24C_ADDRESS 0x50

#define COLOR_DEPTH 16
#define USE_8BPP

#ifdef USE_8BPP
#define SOFTWARE_COLOR_DEPTH 8
#else
#define SOFTWARE_COLOR_DEPTH 16
#endif

#define TFT_WIDTH  240
#define TFT_HEIGHT 320

extern const ButtonInput button_mapping[7][7];

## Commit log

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2021-08-06 Add hardware
    [delta-pico.kicad_pcb, delta-pico.sch]
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2021-08-29 Make sprite full-screen, let Rust know screen sizer
    This has slightly changed how padding looks, but the UI will be laid out differently soon anyway, so it doesn't matter
    [hardware.hpp]
2021-08-30 Add wire fix image
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2021-09-02 Add hardware revision 2
    - Add I2C EEPROM chip
    - Fix missing trace from down button to diode
    - Connect display SD pins
    - Move Pico further to the side to accommodate SD pins
    - Rotate and move expansion socket to not be behind the display
    [delta-pico.kicad_pcb, delta-pico.sch]
2021-09-04 Add beginnings of calculation storage
    Results currently aren't stored! That's next...
    - Add ChunkTable storage abstraction
    - Add Filesystem and CalculationHistory
    - Store calculations when navigating away from them
    - Allow new calculations to be started with EXE
    - Add Memory app for browsing hex
2021-09-04 Add frame timer, using title as the "tick"
2021-09-05 Rename button "poll" to "wait" to better describe it
2021-09-05 Input wait no longer returns an Option
    Also no longer returns None on a button release, which avoids drawing frames twice
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2021-09-06 Reduce display to 8bpp to same memory
    We can't use DMA like this, but we aren't updating the screen fast anyway
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2021-11-07 Experimentally revert to 16bpp mode
    [hardware.hpp]
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2021-11-07 Revert to 8bpp, but somehow icons still look OK...?
    Gray lines are still green, but icons preserve their full colour!
    Wonder if sprites have their own colour space?
    No idea what I have done, but it is good
    [hardware.hpp]
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2021-11-15 Add Rev3, as a KiCad 6 project
    [delta-pico.kicad_pcb, delta-pico.sch]
2021-11-15 Update revision number silkscreen
    [delta-pico.kicad_pcb]
2021-11-15 More KiCad 6 migration
    [delta-pico.kicad_sch, delta-pico.sch]
2021-11-15 Fix footprint for new relative library path
    [delta-pico.kicad_sch]
2021-11-15 Remove through-hole stuff from footprint, update board
    [delta-pico.kicad_pcb, delta-pico.kicad_sch]
2021-11-15 Fix a lot of DRC errors
    [delta-pico.kicad_pcb]
2021-11-15 Make Pico keepout smaller to quieten DRC
    [delta-pico.kicad_pcb]
2021-11-15 Remove pointless via
    [delta-pico.kicad_pcb]
2021-11-15 Add a 6-pin "debug" port, in place of the expansion socket
    [delta-pico.kicad_pcb, delta-pico.kicad_sch]
2021-11-15 Connect PCF8574 interrupt pins to GPIO 16/17
    [delta-pico.kicad_pcb, delta-pico.kicad_sch]
2021-11-15 Break out some bonus GPIO and VIN
    [delta-pico.kicad_pcb, delta-pico.kicad_sch]
2021-11-16 Add a 3D model for the display and use it
    step.py uses FreeCAD to build SCAD into STEP
    [delta-pico.kicad_pcb]
2021-11-16 Add 3D model for buttons
    [delta-pico.kicad_pcb]
2021-11-16 Add Pico model (not mine)
    [delta-pico.kicad_pcb]
2021-11-16 Add js102011saqn model (not mine)
    [delta-pico.kicad_pcb]
2021-11-16 Make board longer for extra mounting holes, tidy up Edge.Cuts
    [delta-pico.kicad_pcb]
2021-11-16 Remove diode silkscreen
    [delta-pico.kicad_pcb]
2021-11-17 Pico calls it VSYS, not VIN
    [delta-pico.kicad_pcb]
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2021-11-21 Add TEXT button in software, and OS toggle
2021-11-21 Replace ButtonInput with OSInput for applications
    Allows Rust-style enum to be used for input
    This will be used for multi-tap
2021-11-21 Make print methods take &str rather than impl Into<String>
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2021-11-27 Add experimental setting to only fire button press events
2021-11-30 Add Schottky diode on VSYS
    [delta-pico.kicad_pcb, delta-pico.kicad_sch]
2021-12-02 Add MOSFET for display power control
    And if that doesn't work, there's a jumper to bypass it
    [delta-pico.kicad_pcb, delta-pico.kicad_sch]
2021-12-02 Make power switch soft
    [delta-pico.kicad_pcb, delta-pico.kicad_sch]
2021-12-02 Remove stray silkscreen
    [delta-pico.kicad_pcb]
2021-12-10 VERY early stages of moving to Pico SDK
    It boots, and the display works, but currently just shows a square
2021-12-20 Slow down I2C bus, 1MHz is way too fast for PCF8574
2021-12-21 Fix antialiased text being too blue (da ba dee da ba di)
2021-12-21 Use larger integers rather than floats for anti-aliasing
    Reduces menu frame time by a third!
2021-12-21 Add battery voltage reading
    Incorrect on Rev.3 due to Schottky, will fix that later
2021-12-21 Fix CAT24C driver - storage now works
2021-12-22 Big refactor
    - Remove animate.hpp, unused for ages
    - Remove application_framework, no longer needed as apps are Rust
    - Fix CAT24C (for real this time!)
    - Clean up sprite destructor
    - Use lambdas for ApplicationFrameworkInterface members
    [hardware.hpp]
2021-12-22 Remove second LUN from example, rename one to Delta Pico
2021-12-22 Use our own PID and VID!
    Thanks pid.codes :)
    Also rename hardware.hpp to hardware.h
2021-12-24 Make this a CDC device as well
    Not having a serial console for debugging is getting annoying!
    I'll try to get printf working at some point.
    Currently this just screams whenever MSC is active
2021-12-24 USB now runs continuously using interrupt and timer
    FAT isn't saved unless user uses "Save" in Storage app
    But that'll be addressed when the driver just uses storage directly
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2021-12-27 Begin adding support for button reading on core 1
    - New mutex for I2C transactions
    - Core 1 builds a queue of button events, which core 0 pulls from
    - Unrelated: added tusb_inited check for debug_handler
    Not great yet since there's a massive "cooldown", but we can build on this!
2021-12-27 Don't allow only one key at a time
    This does work but it's a bit jank
    Honestly I don't think this'll cause any issues unless you are trying to break it
    e.g. The sequence:
    "Press 1", "Press 2", "Release 2", "Release 1"
    Will type "121", with the second erroneous 1 when you "Release 2"
    But the OS doesn't require any button holds, is this ever going to come up?
2021-12-27 Polish revision definitions, add trait for Schottky voltage drop
2021-12-28 Add API for claiming priority for storage on bus
    The new multicore approach caused a regression in speed for storage
    Core 1 hits the bus pretty hard while polling the button matrix!
    Now we can stop it using the bus in storage-heavy sections
    Should probably document this later...
2021-12-29 Add a smaller font, and the ability to switch between them
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2022-03-23 Begin adding test suite with virtual button presses
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2022-03-31 Add fast display draw, remove broken rectangle drawing
    [ili9341.rs, main.rs]
2022-03-31 Fix allocation by setting it up; LED patterns on panic/OOM
    [main.rs]
2022-03-31 Add PCF8574 driver and use it for prototype buttons
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2022-04-01 Add delays to fix ILI9341
    block! doesn't block properly for writes
    [ili9341.rs]
2022-04-01 Rename HAL Colour to RawColour, fix translation
    RawColour matches how the display wants colour
    [graphics.rs, ili9341.rs, main.rs]
2022-04-02 90% of the way to working buttons
    Still need:
    - A keymap (everything currently works as EXE)
    - poll_event implementation
2022-04-02 Add button mapping and fix repeating
    [button_matrix.rs, main.rs]
2022-04-02 Use correct hardware revision text
    [main.rs]
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2022-04-03 Fix rectangle clipping on Y axis
    [graphics.rs]
2022-04-04 Use a crate to replace SaturatingInto
    [graphics.rs]
2022-04-05 Calculator nearly working!
    Calculation save and load is broken
    [graphics.rs, main.rs]
2022-04-06 Re-add delays from old storage driver
    Hopefully fixes issue with some calculations not saving
    [cat24c.rs, main.rs]
2022-04-06 Remove CMake project
    You served me well, Pico SDK :)
2022-04-06 rust-analyzer warning fix and cleanup pass
    [button_matrix.rs, cat24c.rs]
2022-04-06 Fix OS clippy lints
    [graphics.rs]
2022-04-12 Switch to RGB332 colour
    Huge memory saving, and still looks good!
2022-04-13 Add square roots
    Bit of clunk involving the cursor because we can't declare that we want end-padding, but that'll need fixes in rbop
    [graphics.rs]
2022-04-13 Switch to a grey which shows up better in RGB332
2022-06-03 Don't panic if one button reading fails
    [main.rs]
2022-06-03 Don't fail cast on non-ASCII character in string_size
    [graphics.rs]
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2022-07-01 Re-add basic testing
    Due to lifetime issues, now done with framework-specific trigger
    For hardware, this is holding DEL on boot
    Simulator will probably be a flag or something
    [main.rs]
2022-07-04 Add optional framework item `tests_success_hook`
    Mainly so simulator can exit on completion
2022-07-04 Add better bounds to `try_pixel_immutable`
    Fixes panic when `ui_input_expression` overflows viewport
    [sprite.rs]
2022-07-05 Fix frame time, move it and memory usage to separate panels
    Frame time now measured from input completion to os.draw() call
2022-07-05 Compute each screen Y only once
    This is a surprisingly expensive operation!
    Takes sin(x) plot line timer from ~427ms to ~267ms
2022-07-06 Add a common trait for menus
    Currently working on a better context menu, so allows for some shared logic
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2022-07-08 Correctly synchronise core 1 boot
    [main.rs]
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2022-07-11 Add a 3D-printable baseplate for rev. 3
    [case.scad]
2022-07-12 Minor case sizing adjustments
    [case.scad]
